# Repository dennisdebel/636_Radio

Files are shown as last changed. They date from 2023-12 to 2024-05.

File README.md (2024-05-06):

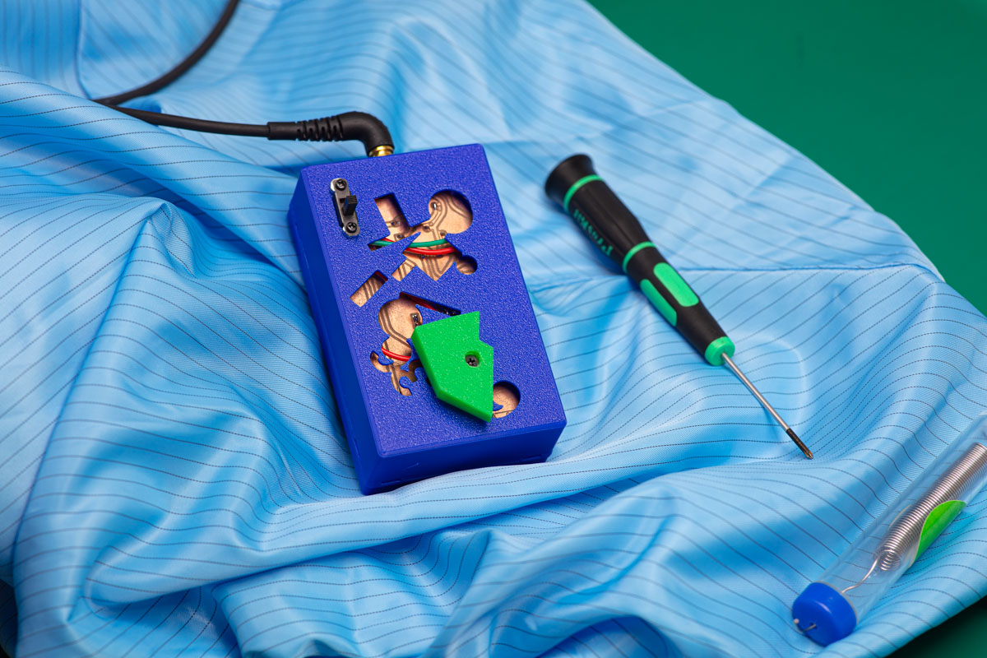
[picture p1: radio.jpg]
Assembled radio


# 636_Radio
Modern replica of China's first domestically produced single transistor AM radio

## PCB / Gerbers
This replica is deisgned in a way it is easy to solder for beginners on a pcb made 'at home'. This means, optimized for single side copper clad boards.
The pcb is designed in KiCad. If you want to produce this board directly, the latest 'gerber' files can be found [here](https://github.com/dennisdebel/636_Radio/tree/main/gerbers-may6-2024)

## Case
The [case](https://github.com/dennisdebel/636_Radio/tree/main/636-radio-case) and tuner button are designed in OpenSCAD based on the excellent [YAPP_box](https://github.com/mrWheel/YAPP_Box) (Yet Another Parametric Projectbox generator). Find the printable box [here](https://github.com/dennisdebel/636_Radio/blob/main/636-radio-case/636-radio-case-2.1.stl)

## Bill Of Materials
The bill of materials and interactive assembly guide can be found [here](bom/ibom.html). Please ignore the footprint names of some of the components, namely C1 (this is a variable capacitor) and L1 (AM ferrite antenna).

Let me know if you have any issues, suggestions and/or questions!

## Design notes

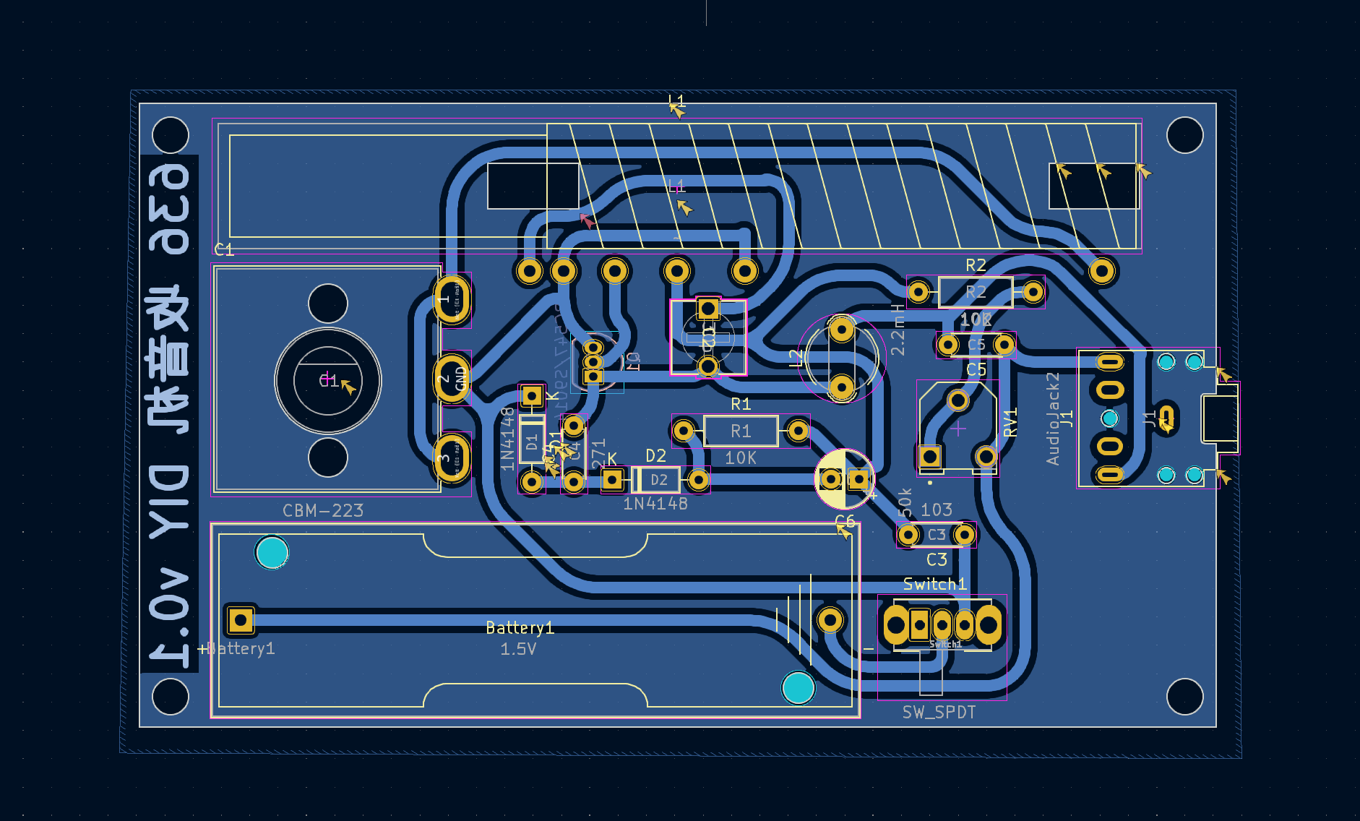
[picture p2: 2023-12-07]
reference-image.png

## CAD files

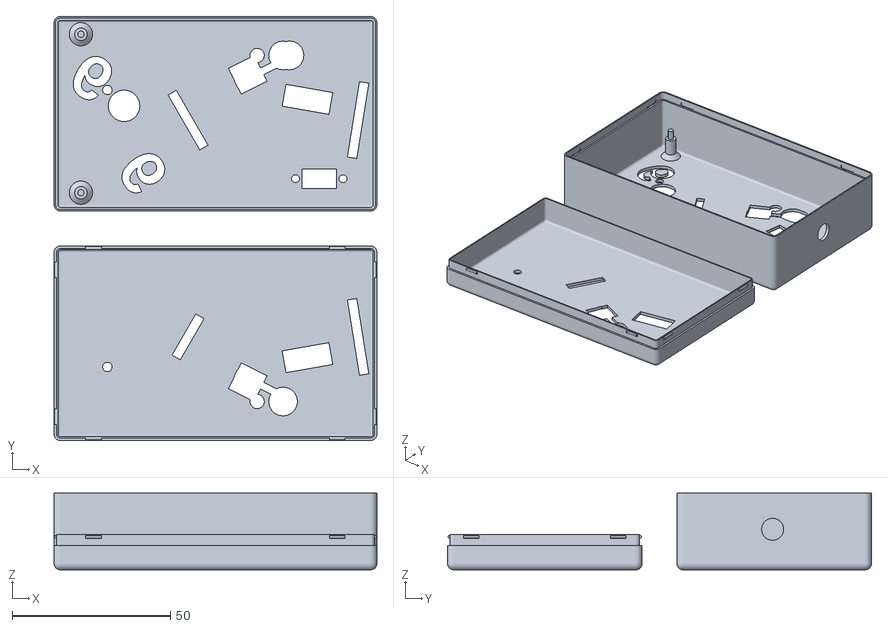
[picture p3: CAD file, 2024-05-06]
636-radio-case/636-radio-case-2.1.stl
101.9 x 133.8 x 24.2

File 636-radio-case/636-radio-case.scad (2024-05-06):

//---------------------------------------------------------
// This design is parameterized based on the size of a PCB.
//---------------------------------------------------------
include <library/YAPPgenerator_v16.scad>

// Note: length/lengte refers to X axis, 
//       width/breedte to Y, 
//       height/hoogte to Z

/*
      padding-back|<------pcb length --->|<padding-front
                            RIGHT
        0    X-as ---> 
        +----------------------------------------+   ---
        |                                        |    ^
        |                                        |   padding-right 
        |                                        |    v
        |    -5,y +----------------------+       |   ---              
 B    Y |         | 0,y              x,y |       |     ^              F
 A    - |         |                      |       |     |              R
 C    a |         |                      |       |     | pcb width    O
 K    s |         |                      |       |     |              N
        |         | 0,0              x,0 |       |     v              T
      ^ |   -5,0  +----------------------+       |   ---
      | |                                        |    padding-left
      0 +----------------------------------------+   ---
        0    X-as --->
                          LEFT
*/


//-- which half do you want to print?
printLidShell       = true;
printBaseShell      = true;

//-- Edit these parameters for your own board dimensions
wallThicknss       = 1.8;
basePlaneThickness  = 1.2;
lidPlaneThickness   = 1.2;

//-- Total height of box = basePlaneThickness + lidPlaneThickness 
//--                     + baseWallHeight + lidWallHeight
//-- space between pcb and lidPlane :=
//--      (baseWallHeight+lidWallHeight) - (standoffHeight+pcbThickness)
baseWallHeight      = 10;
lidWallHeight       = 20;

//-- ridge where base and lid off box can overlap
//-- Make sure this isn't less than lidWallHeight
ridgeHeight         = 3.5;
ridgeSlack          = 0.4;
roundRadius         = 2.0;

//-- pcb dimensions
pcbLength           = 95.5;
pcbWidth            = 55;
pcbThickness        = 1.5;

//-- How much the PCB needs to be raised from the base
//-- to leave room for solderings and whatnot
standoffHeight      = 7.8; //5.1
pinDiameter         = 2.0;
pinHoleSlack        = 0.5;
standoffDiameter    = 4;
standoffSupportHeight   = 2.0;
standoffSupportDiameter = 2.0;
                            
//-- padding between pcb and inside wall
paddingFront        = 2;
paddingBack         = 2;
paddingRight        = 2;
paddingLeft         = 2;


//-- D E B U G ----------------------------
showSideBySide      = true;       //-> true
onLidGap            = 0;
shiftLid            = 1;
hideLidWalls        = false;       //-> false
colorLid            = "yellow";   
hideBaseWalls       = false;       //-> false
colorBase           = "white";
showPCB             = false;      //-> false
showMarkers         = false;      //-> false
inspectX            = 0;  //-> 0=none (>0 from front, <0 from back)
inspectY            = 0;
//-- D E B U G ----------------------------


//-- pcb_standoffs  -- origin is pcb[0,0,0]
// (0) = posx
// (1) = posy
// (2) = { yappBoth | yappLidOnly | yappBaseOnly }
// (3) = { yappHole, YappPin }
pcbStands = [
                //[10, 10 ,yappLidOnly,yappPin], //does not work
               //[93, 125 ,yappBaseOnly,yappPin], // front right - hack to put YappPin on lid..
                 [5.3, 125 ,yappBaseOnly,yappPin], //back right
                  [5.3, 75 ,yappBaseOnly,yappPin], //back left
                  //[93, 75 ,yappBaseOnly,yappPin] //front left
             ];

//-- Lid plane    -- origin is pcb[0,0,0]
// (0) = posx
// (1) = posy
// (2) = width
// (3) = length
// (4) = angle
// (5) = { yappRectangle | yappCircle }
// (6) = { yappCenter }

cutoutsLid =  [ 
    //speaker holes
   // rotate((j*360)/3)

			 // [70, pcbWidth/2+4, 2, 0, 0, yappCircle],
             
//     [70, pcbWidth/2, 2, 0, 0, yappCircle],
//        [70, pcbWidth/2+3, 2, 0, 0, yappCircle],
//        [70, pcbWidth/2-3, 2, 0, 0, yappCircle],
//     [70-3, pcbWidth/2-1, 2, 0, 0, yappCircle],
//     [70+3, pcbWidth/2+1, 2, 0, 0, yappCircle],
//        [70-3, pcbWidth/2+2, 2, 0, 0, yappCircle],
//        [70+3, pcbWidth/2-2, 2, 0, 0, yappCircle],
//            [70-3, pcbWidth/2+5, 2, 0, 0, yappCircle],
//            [70+3, pcbWidth/2-5, 2, 0, 0, yappCircle],
     
    // on/off swicth
                   [73, 48, 2.5, 0, 0, yappCircle],
                   [88, 48, 2.5, 0, 0, yappCircle],
                   [75, 45, 6, 11, 0, yappRectangle], 
           
    // tuner capacitor
                  [18.9, pcbWidth/2-2.5, 10, 0, 0, yappCircle],
                  
                  
   // wild style
        [70*single_rand_small, single_rand_small,single_rand_small/2, single_rand_small, single_rand_big, yappRectangle],
        
        [60, single_rand_small,single_rand_small, single_rand_small, single_rand_big+10, yappRectangle],
        
        [55, single_rand_small+single_rand_big,single_rand_small, single_rand_small/3, single_rand_big+10, yappRectangle],
        
        
       [70-single_rand_small, single_rand_small,single_rand_small/2, single_rand_small, single_rand_big, yappCircle],
        
        [60+single_rand_small, single_rand_small,single_rand_small, single_rand_small, single_rand_big+10, yappCircle],
        
        [55-single_rand_small, single_rand_small+single_rand_big,single_rand_small, single_rand_small/3, single_rand_big+10, yappCircle],
        
//--

        [50*single_rand_small, single_rand_small,single_rand_small/2, single_rand_small, single_rand_big, yappRectangle],
        
        [60+10, single_rand_small,single_rand_small*2, single_rand_small/4, single_rand_big+10, yappRectangle],
        
        [55*single_rand_small, single_rand_small*single_rand_big,single_rand_small, single_rand_small/2, single_rand_big-10, yappRectangle],
        
        
       [70*single_rand_small, single_rand_small*2,single_rand_small/3, single_rand_small, single_rand_big, yappCircle],
        
        [60+single_rand_small+2, single_rand_small,single_rand_small, single_rand_small, single_rand_big+5, yappCircle],
        
        [55-single_rand_small, single_rand_small+single_rand_big,single_rand_small, single_rand_small/4, single_rand_big-20, yappCircle]
       
        //---
        
      ,[pcbLength-9*single_rand_small, 20, 3, 0, 0, yappCircle] 
      ,[60*single_rand_small, pcbWidth/2, 5, 9, -10, yappRectangle, yappCenter],
            [70, 2*single_rand_small, 7, 15, 10, yappRectangle]
      ,[pcbLength-19*single_rand_small-10, 20, 6, 0, 0, yappCircle] 
      ,[30+single_rand_small, pcbWidth/2+2, 20, 3, -30, yappRectangle, yappCenter]
      
               ,[30+single_rand_small+single_rand_big, pcbWidth/2+2, 15+single_rand_small, 3, single_rand_small, yappRectangle, yappCenter]
                
              ];
              

//-- base plane    -- origin is pcb[0,0,0]
// (0) = posx
// (1) = posy
// (2) = width
// (3) = length
// (4) = angle
// (5) = { yappRectangle | yappCircle }
// (6) = { yappCenter }
cutoutsBase = [
//                    [10, 10, 10, 15, 30, yappRectangle]
//                  , [10, 10, 5, 0, 0, yappCircle]
//                  , [pcbLength/2, pcbWidth/2, 10, 15, 45, yappRectangle, yappCenter]
//                  , [pcbLength/2, pcbWidth/2, 5, 0, 0, yappCircle]

   // wild style
        [70*single_rand_small, single_rand_small,single_rand_small/2, single_rand_small, single_rand_big, yappRectangle],
        
        [60, single_rand_small,single_rand_small, single_rand_small, single_rand_big+10, yappRectangle],
        
        [55, single_rand_small+single_rand_big,single_rand_small, single_rand_small/3, single_rand_big+10, yappRectangle],
        
        
       [70-single_rand_small, single_rand_small,single_rand_small/2, single_rand_small, single_rand_big, yappCircle],
        
        [60+single_rand_small, single_rand_small,single_rand_small, single_rand_small, single_rand_big+10, yappCircle],
        
        [55-single_rand_small, single_rand_small+single_rand_big,single_rand_small, single_rand_small/3, single_rand_big+10, yappCircle],
        
//--
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

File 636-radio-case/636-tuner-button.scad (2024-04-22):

// hardware needed: 2.4mm x 11.6mm bolt 
//vars
    //quality
    $fn=30;
//random numbers for unique boxes
    rand1 = rands(0,3,1)[0];
    rand2 = rands(0,1.2,1)[0];



difference(){ //hole
        
    //========= KNOB + SHAFT =========
    union(){

        //========= KNOB =========
        //we generate a random shape for each render
        translate([5,0,-10])
            linear_extrude(height = 6, twist = rand1+2, slices = 20) 
            {
                minkowski()
                {
                    polygon(points=[

                        [-13*rand1,-13*rand2],
                        [-4,13*rand2],
                        [-13,13*rand2],
                        ]);
                        
                        polygon(points=[
                        
                        [rand1,13*rand1],
                        [13+rand1,4],
                        [rand1,-10*rand2],
                        [4,-13*rand1]]);
                }
        }
        //========= SHAFT =========
        difference(){ //shaft
            //shaft
            translate([0,0,0.5])
            cylinder(10,4.3,4.3, center=true); //cut sides off this cylinder

 translate([0,0,5])
            difference(){ // cut off sides
                cylinder(3,3.3,3.3, center=true); //cut sides off this cylinder
                   difference(){ //sides that need cutting off
                        cylinder(3,3.3,3.3, center=true);
                        cube([4.8,7,4],center=true); 
                    }
            }

        }
    } //union shaft + knob

    translate([0,0,-12])
    cylinder(6,6.5,6.5, center=true); // countersink for mounting screw
    cylinder(20,1.5,1.5, center=true); // hole for mounting screw

} //cut screw hole
    

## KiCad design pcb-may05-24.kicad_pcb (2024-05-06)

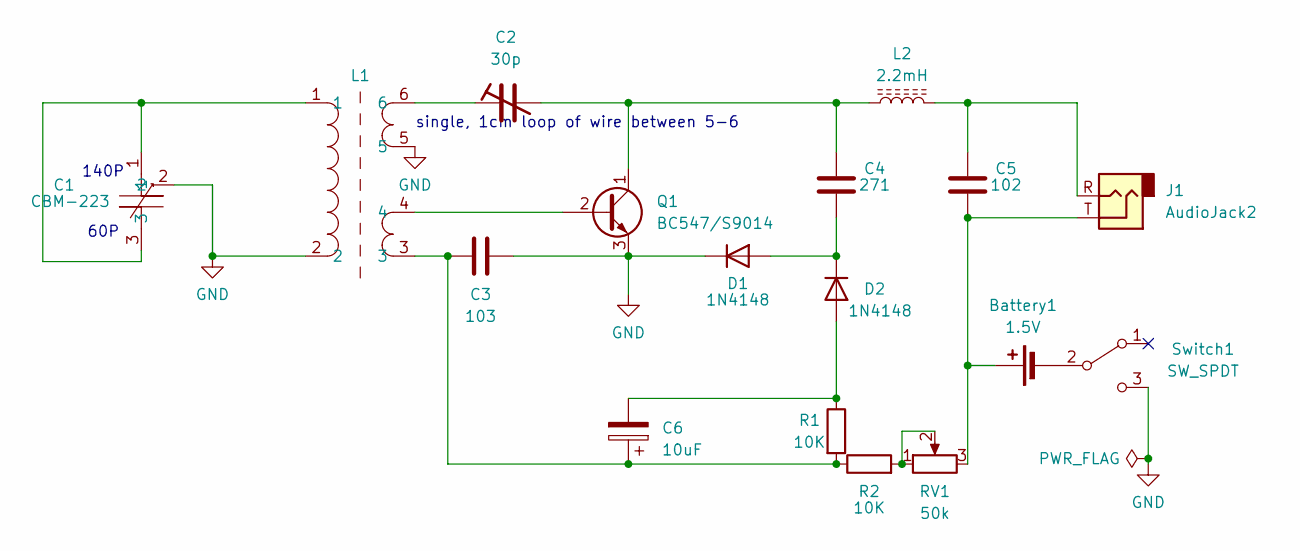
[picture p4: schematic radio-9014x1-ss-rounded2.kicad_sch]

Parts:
Battery1: 1.5V; BatteryHolder_Keystone_2460_1xAA
C1: CBM-223; RotaryEncoder_Bourns_Vertical_PEC12R-3x17F-Sxxxx
C2: 30p; VCAP_GKGXXX15_SGM
C3: 103; C_Disc_D4.3mm_W1.9mm_P5.00mm
C4: 271; C_Disc_D4.3mm_W1.9mm_P5.00mm
C5: 102; C_Disc_D4.3mm_W1.9mm_P5.00mm
C6: 10uF; CP_Radial_D5.0mm_P2.50mm
D1, D2: 1N4148; D_DO-35_SOD27_P7.62mm_Horizontal
J1: AudioJack2; Jack_3.5mm_CUI_SJ1-3525N_Horizontal
L1: L_CommonMode_Toroid_Vertical_L43.2mm_W22.9mm_Px17.78mm_Py30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
L2: 2.2mH; LairdTech_28C0236-0JW-10
Q1: BC547/S9014; TO-92_Inline_Wide
R1, R2: 10K; R_Axial_DIN0207_L6.3mm_D2.5mm_P10.16mm_Horizontal
RV1: 50k; TRIM_3306F-1-503
Switch1: SW_SPDT; SW_CuK_OS102011MA1QN1_SPDT_Angled

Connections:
GND: C1.2, C3.1, D1.1 (K), L1.2, L1.5, Q1.3 (E), Switch1.3 (C)
unnamed: Battery1.1 (+), C5.1, J1.T, RV1.3
unnamed: Battery1.2 (-), Switch1.2 (B)
unnamed: C1.1, C1.3, L1.1
unnamed: C2.1, L1.6
unnamed: C3.2, C6.1, L1.3, R1.2, R2.1
unnamed: C5.2, J1.R, L2.2
unnamed: C4.1, D1.2 (A), D2.1 (K)
unnamed: C6.2, D2.2 (A), R1.1
unnamed: L1.4, Q1.2 (B)
unnamed: C2.2, C4.2, L2.1, Q1.1 (C)
unnamed: R2.2, RV1.1, RV1.2

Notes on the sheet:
140P
60P
single, 1cm loop of wire between 5-6


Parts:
Battery1: 1.5V; BatteryHolder_Keystone_2460_1xAA
C1: CBM-223; RotaryEncoder_Bourns_Vertical_PEC12R-3x17F-Sxxxx
C2: 30p; VCAP_GKGXXX15_SGM
C3: 103; C_Disc_D4.3mm_W1.9mm_P5.00mm
C4: 271; C_Disc_D4.3mm_W1.9mm_P5.00mm
C5: 102; C_Disc_D4.3mm_W1.9mm_P5.00mm
C6: 10uF; CP_Radial_D5.0mm_P2.50mm
D1, D2: 1N4148; D_DO-35_SOD27_P7.62mm_Horizontal
J1: AudioJack2; Jack_3.5mm_CUI_SJ1-3525N_Horizontal
L1: L_CommonMode_Toroid_Vertical_L43.2mm_W22.9mm_Px17.78mm_Py30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
L2: 2.2mH; LairdTech_28C0236-0JW-10
Q1: BC547/S9014; TO-92_Inline
R1, R2: 10K; R_Axial_DIN0207_L6.3mm_D2.5mm_P10.16mm_Horizontal
RV1: 50k; TRIM_3306F-1-503
Switch1: SW_SPDT; SW_CuK_OS102011MA1QN1_SPDT_Angled

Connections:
GND: C1.2, C3.1, D1.1 (K), L1.2, L1.5, Q1.3 (E), Switch1.3 (C)
unnamed: Battery1.1 (+), C5.1, J1.T, RV1.3
unnamed: Battery1.2 (-), Switch1.2 (B)
unnamed: C1.1, C1.3, L1.1
unnamed: C2.1, L1.6
unnamed: C3.2, C6.1, L1.3, R1.2, R2.1
unnamed: C5.2, J1.R, L2.2
unnamed: C4.1, D1.2 (A), D2.1 (K)
unnamed: C6.2, D2.2 (A), R1.1
unnamed: L1.4, Q1.2 (B)
unnamed: C2.2, C4.2, L2.1, Q1.1 (C)
unnamed: R2.2, RV1.1, RV1.2

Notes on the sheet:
140P
60P
single, 1cm loop of wire between 5-6

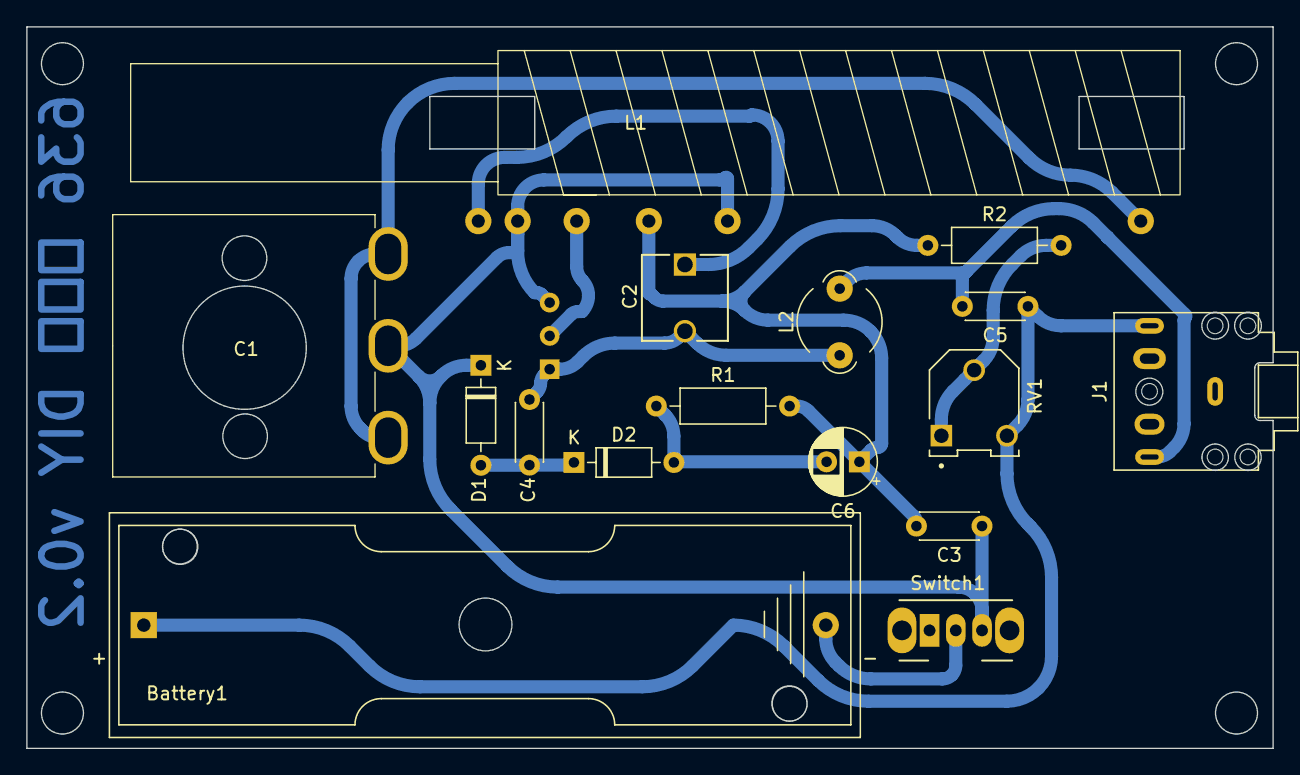
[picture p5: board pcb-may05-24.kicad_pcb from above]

Board: 2 copper layers, 95.0 x 55.0 mm, 17 parts (1 on the bottom side), 12 nets.

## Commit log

2023-12-07 added kicad project files
    [radio-9014x1-ss-rounded2.kicad_pcb, radio-9014x1-ss-smooth.kicad_pcb, radio-9014x1-ss.kicad_pcb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]
2024-01-08 Easier soldering
    Edited transistor footprint to the 'wide' variety for easier soldering
    [radio-9014x1-ss-rounded2.kicad_pcb, radio-9014x1-ss-rounded2.kicad_sch, radio-9014x1-ss-smooth.kicad_pcb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]
2024-04-19 added files for 3d printable case
    [636-radio-case.scad, 636-tuner-button.scad]
2024-04-22 fine tuned case designs
    [636-radio-case.scad, 636-tuner-button.scad]
2024-04-23 updated pcb
    wider transistor footprint for easier soldering
    [radio-9014x1-ss-rounded2.kicad_pcb, radio-9014x1-ss-wide-transistor.kicad_pcb]
2024-04-23 added production gerbers
    If manually cnc this, select a copper bottom template
    [radio-9014x1-ss-wide-transistor-B_Cu.gbr, radio-9014x1-ss-wide-transistor-Edge_Cuts.gbr, radio-9014x1-ss-wide-transistor-drl_map.gbr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]
2024-04-27 added slack
    on ridge and standoffs (give some room to the on/off switch)
    [636-radio-case.scad]
2024-05-06 Easier hand soldering
    [pcb-may05-24.kicad_pcb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]
2024-05-06 Updated case
    To better facilitate on/off button
    [636-radio-case-2.1.stl, 636-radio-case.scad]
2024-05-06 Added assembly instructions
2024-05-06 Added some notes on the BOM
